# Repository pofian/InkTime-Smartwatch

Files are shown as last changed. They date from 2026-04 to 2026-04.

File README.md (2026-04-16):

# InkTime - Smartwatch

InkTime is an open-source, ultra-low-power smartwatch built around the Nordic nRF52840 SoC. It features a 1.54" E-Paper display, integrated battery management, and environmental/motion sensors, all optimized for extended battery life and BLE connectivity.

---

## Hardware Architecture

### Block Diagram

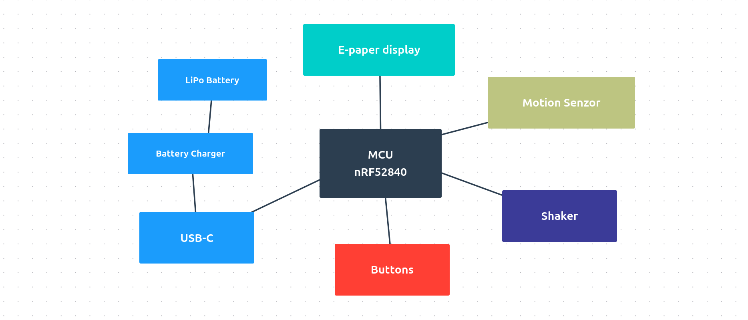
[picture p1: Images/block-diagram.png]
Block Diagram


---

## Bill of Materials

| Reference Designators | Quantity | Description | Package | Value | Manufacturer | Manufacturer Part Number | Vendor | Vendor Part Number | Top/Bottom | |
|---|---|---|---|---|---|---|---|---|---|---|
| | 1 | PCB Board | Board | | | | | | | |
| ANT1 | 1 | Antennas 2.45GHz ANTENNA | 2450AT18B100E_ANTC3216X140N | 2450AT18B100E_2450AT18B100E | | | | | Top | |
| C1, C2, C17, C18 | 4 | Generic chip capacitor | NORDIC_NRF_3_RESC0201_L | 12pF | | | | | Top | |
| C1-EP-DR, C24, C39 | 3 | CAPACITOR, European symbol | ESP32_WROVER_EAGLE-LTSPICE_C0402 | 10uF | | | | | Top | |
| C2-EP-DR | 1 | CAPACITOR, European symbol | ESP32_WROVER_EAGLE-LTSPICE_C0402 | 4.7uF/25V | | | | | Top | |
| C3, C4 | 2 | Generic chip capacitor | NORDIC_NRF_3_RESC0201_L | 1pF | | | | | Top | |
| C5, C7, C8, C12, C19 | 5 | Generic chip capacitor | NORDIC_NRF_3_RESC0201_L | 100nF | | | | | Top | |
| C6, C14, C20, C21 | 4 | Generic chip capacitor | NORDIC_NRF_3_RESC0201_L | 4.7μF | | | | | Top | |
| C9 | 1 | Generic chip capacitor | NORDIC_NRF_3_RESC0201_L | 820pF | | | | | Top | |
| C10, C13, C22 | 3 | Generic chip capacitor | NORDIC_NRF_3_RESC0201_L | N.C. | | | | | Top | |
| C11 | 1 | Generic chip capacitor | NORDIC_NRF_3_RESC0201_L | 100pF | | | | | Top | |
| C15 | 1 | Generic chip capacitor | NORDIC_NRF_3_RESC0201_L | 1.0μF | | | | | Top | |
| C16 | 1 | Generic chip capacitor | NORDIC_NRF_3_RESC0201_L | 47nF | | | | | Top | |
| C23 | 1 | Check availability | CAPC0201X13N | 0.1uF | | | | | Top | |
| C25, C33 | 2 | CAPACITOR, European symbol | ESP32_WROVER_EAGLE-LTSPICE_C0402 | 22uF | | | | | Top | |
| C27, C34 | 2 | Generic chip capacitor | NORDIC_NRF_3_RESC0201_L | 0.1uF | | | | | Top | |
| C29, C30, C31, C43 | 4 | CAPACITOR, European symbol | ESP32_WROVER_EAGLE-LTSPICE_C0402 | | | | | | Top | |
| C32, C37, C38 | 3 | CAPACITOR, European symbol | ESP32_WROVER_EAGLE-LTSPICE_C0402 | 1uF | | | | | Top | |
| C42 | 1 | Generic chip capacitor | NORDIC_NRF_3_RESC0201_L | | | | | | Top | |
| D2, D4, D5 | 3 | ON SEMICONDUCTOR - MBR0530 - DIODE, SCHOTTKY, 0.5A, 30V, SOD-123 | SOD3716X135N | ESP32_C6_LIBRARY_5_MBR0530 | | | | | Top | |
| D3 | 1 | Low Cap. ESD Protection Auto SOT-23-6 STMicroelectronics USBLC6-2SC6Y, Dual Uni-Directional TVS Diode Array, 6-Pin SOT-23 | SOT95P280X145-6N | ESP32_C6_LIBRARY_3_USBLC6-2SC6Y | | | | | Top | |
| EPD_C1, EPD_C2, EPD_C6, EPD_C7, EPD_C8, EPD_C9, EPD_C10, EPD_C11, EPD_C12 | 9 | CAPACITOR, European symbol | ESP32_WROVER_EAGLE-LTSPICE_C0402 | 1uF/50V | | | | | Top | |
| EPD_C5 | 1 | CAPACITOR, European symbol | ESP32_WROVER_EAGLE-LTSPICE_C0402 | 0.1uF/50V | | | | | Top | |
| IC1 | 1 | Charger IC Lithium Ion/Polymer, Lithium Iron Phosphate 8-DSBGA (1.6x1.1) | BQ25180YBGR_BGA8C40P2X4_100X155X50 | BQ25180YBGR_BQ25180YBGR | | | | | Top | |
| IC2 | 1 | Haptic Driver for ERM/LRA with Built-In Library and Smart Loop Architecture | DRV2605YZFR_BGA9C50P3X3_144X144X62 | DRV2605YZFR_DRV2605YZFR | | | | | Top | |
| IC3 | 1 | Accelerometers Triaxial low-g 12bit Acceleration Sensor | BMA423_BMA423 | BMA423_BMA423 | | | | | Top | |
| IC9 | 1 | Buck-Boost Regulator Positive Output Step-Up/Step-Down I2C DC-DC Controller IC 15-WL-CSP (BSC) (1.4x2.3) | RT6160AWSC_BGA15C40P3X5_140X230X60 | RT6160AWSC_RT6160AWSC | | | | | Top | |
| J1 | 1 | FFC & FPC Connectors 0.5mm FPC RA SMT Dual Contact 24Ckt | 503480-2400_5034802400 | 503480-2400_503480-2400 | | | | | Top | |
| J2 | 1 | CABLE ADAPTER 6 POS | TC2030-IDC_TC2030IDC | TC2030-IDC_TC2030-IDC | | | | | Top | |
| J4 | 1 | Check availability | KINGHELM_KH-TYPE-C-16P | KH-TYPE-C-16P_KH-TYPE-C-16P | | | | | Top | |
| L1, L7 | 2 | Generic chip inductor | NORDIC_NRF_2_RESC0402_L | | | | | | Top | |
| L2 | 1 | Generic chip inductor | NORDIC_NRF_2_RESC0402_L | 10uH | | | | | Top | |
| L3 | 1 | Generic chip inductor | NORDIC_NRF_2_RESC0402_L | 15nH | | | | | Top | |
| L5 | 1 | Generic chip inductor | NORDIC_NRF_2_RESC0402_L | 68uH | | | | | Top | |
| Q1 | 1 | P-channel MOSFETs | ESP32_WROVER_SPARKFUN-DISCRETESEMI_SOT23-3 | 20V/4.2A/52mΩ/1.4W | | | | | Top | |
| Q3 | 1 | MOSFET N-Ch 30V 1.5A TrenchFET SC70 Vishay Si1308EDL-T1-GE3 N-channel MOSFET Transistor, 1.5 A, 30 V, 3-Pin SC-70 | SOT65P210X110-3N | ESP32_C6_LIBRARY_6_SI1308EDL-T1-GE3 | | | | | Top | |
| R_PWR_EPD, R2_EP_DR, R5, R7, R8, R9 | 6 | 7.68k 0201 Thin Film Surface Mount Fixed Resistor +/-0.5% 0.031W CPF0201D7K68C1 | CPF0201D7K68C1_0201 | 10K | | | | | Top | |
| R_TYPE_SEL | 1 | 7.68k 0201 Thin Film Surface Mount Fixed Resistor +/-0.5% 0.031W CPF0201D7K68C1 | CPF0201D7K68C1_0201 | 2.2 | | | | | Top | |
| R1_EP_DR | 1 | 7.68k 0201 Thin Film Surface Mount Fixed Resistor +/-0.5% 0.031W CPF0201D7K68C1 | CPF0201D7K68C1_0201 | 0.47 | | | | | Top | |
| R1_USB, R2_USB | 2 | 7.68k 0201 Thin Film Surface Mount Fixed Resistor +/-0.5% 0.031W CPF0201D7K68C1 | CPF0201D7K68C1_0201 | 5K1 | | | | | Top | |
| R2, R4 | 2 | 7.68k 0201 Thin Film Surface Mount Fixed Resistor +/-0.5% 0.031W CPF0201D7K68C1 | CPF0201D7K68C1_0201 | 0 | | | | | Top | |
| R3 | 1 | 7.68k 0201 Thin Film Surface Mount Fixed Resistor +/-0.5% 0.031W CPF0201D7K68C1 | R0201 | 0 | | | | | Top | |
| R17, R18 | 2 | 7.68k 0201 Thin Film Surface Mount Fixed Resistor +/-0.5% 0.031W CPF0201D7K68C1 | CPF0201D7K68C1_0201 | 3K3 | | | | | Top | |
| SJ1 | 1 | SMD solder JUMPER | JUMPER_SJ | | | | | | Top | |
| SW_DN, SW_ENT, SW_UP | 3 | | SW_EVP-AKE31A_PAN | 2025-10-22_07-23-44_LIBRARY_EVP-AKE31ASW_EVP-AKE31A_PAN | | | | | Top | |
| TP_3.3V, TP_3V3, TP_BAT_GND, TP_GND, TP_ON, TP_OP, TP_RESET, TP_SCL, TP_SDA, TP_SWDCLK, TP_SWDIO, TP_SWO, TP_VBAT, TP_VREG | 14 | Test pad | HECTOR_WATCH_1_TP20R | HECTOR_WATCH_1_TPTP20R | | | | | Top | |
| U1 | 1 | nRF52840 | NORDIC_NRF_4_AQFN50P700X700X85_HS-74N | NORDIC_NRF_4_NRF52840_QF | | | | | Top | |
| U3 | 1 | Check availability | SON50P200X200X80-9N | ESP32_C6_LIBRARY_MAX17048G+T10 | | | | | Top | |
| X1 | 1 | | NORDIC_NRF_BT-XTAL_2016_N | 32MHz | | | | | Top | |
| X2 | 1 | | NORDIC_NRF_1_XTAL_3215_N | | | | | | Top | |

---

## Hardware Functionality

### 1. Power Architecture
The system is powered by a 250mAh LiPo battery.

* **Charging:** The BQ25180 manages 5V input from USB-C. It features I2C configurable charge currents and safety timers.
* **Regulation:** A high-efficiency RT6160 buck-boost converter provides a stable 3.3V rail. This maintains 3.3V even when the battery drops to 3.0V.
* **Monitoring:** The MAX17048 uses the ModelGauge algorithm to provide precise SOC (State of Charge) data.

### 2. Display System
A 1.54" E-Paper display (200x200) is used for zero power consumption when static.

* **Interface:** 4-wire SPI + DC/RST/BUSY control lines.
* **Booster Circuit:** An external inductor-based boost circuit generates the ±15V gates voltages required for the e-ink capsules.

### 3. Sensors and Feedback
* **IMU:** The BMA423 provides step counting and tilt-to-wake functionality via I2C interrupts.
* **Haptics:** The DRV2605 drives a 10mm coin vibration motor, providing tactile effects.

---

## Design Log & Decisions

### DRC Exceptions
The following errors were reviewed and manually accepted in the final design:

* **Pad-to-Trace Clearance:** Errors caused by traces passing between MCU pads; these are unavoidable due to the high-density pinout and the limited routing escape paths of the nRF52840 package.
* **Via Proximity:** Errors caused by vias placed in close proximity to each other, necessitated by the same spatial constraints in the micro-pitch area of the SoC.

### Layout Decisions
* **Stack-up:** 4-layer PCB to ensure a solid GND plane (Layer 2) for RF performance.
* **Power Traces:** All power rails (VBUS, VBAT, 3V3, etc.) use a 0.3mm width for current spikes.
* **Signal Integrity:** Data signals use 0.15mm width. No 90-degree angles were used; all corners are 45 degrees.

### Mechanical Placement
* **USB-C Port:** Centered on the top edge, slightly protruding from the PCB boundary for seamless enclosure alignment.
* **User Input:** Three tactile buttons are located on the bottom edge.

### Polygon & Outline Management
* **GND Polygon Overlaps:** Same-net (GND) clearance warnings between overlapping polygons on different layers were ignored as they pose no electrical risk.

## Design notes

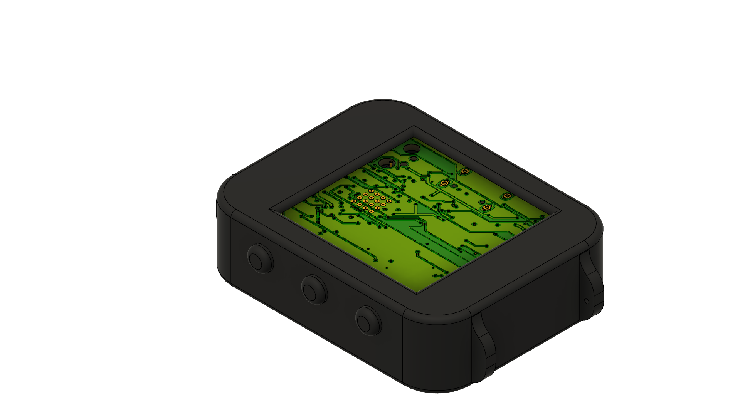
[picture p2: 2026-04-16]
Images/watch1.png

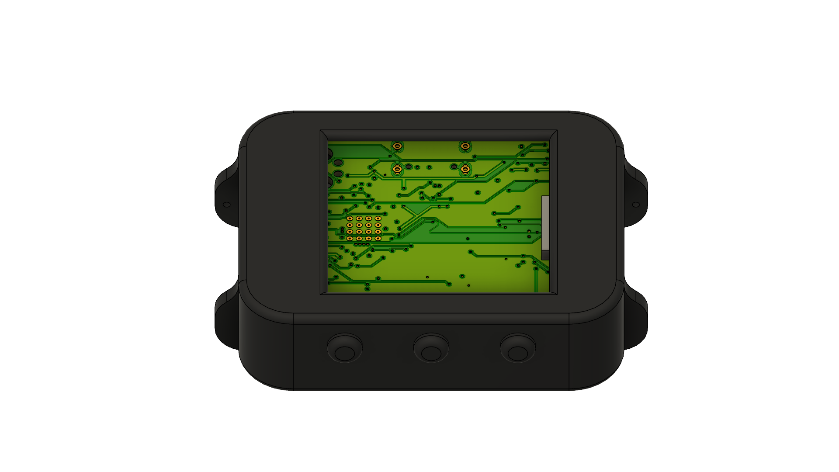
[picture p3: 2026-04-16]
Images/watch2.png

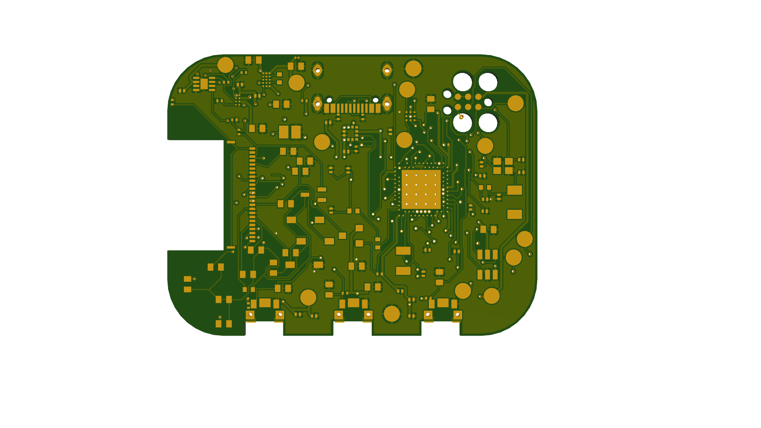
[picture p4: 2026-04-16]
Images/pcb-top.png

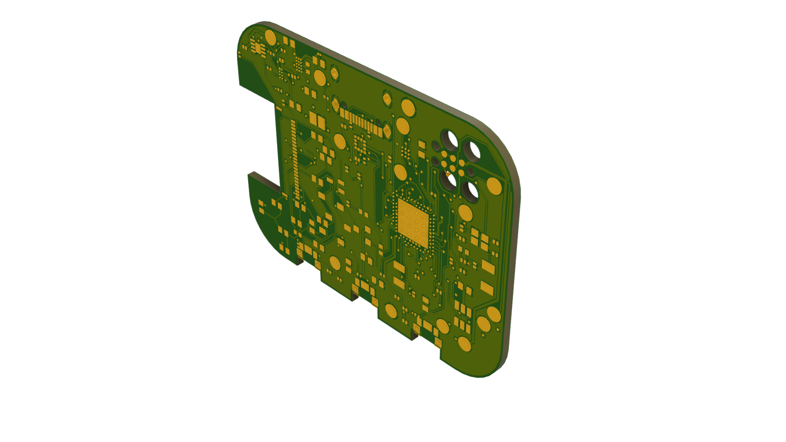
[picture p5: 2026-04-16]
Images/pcb.png

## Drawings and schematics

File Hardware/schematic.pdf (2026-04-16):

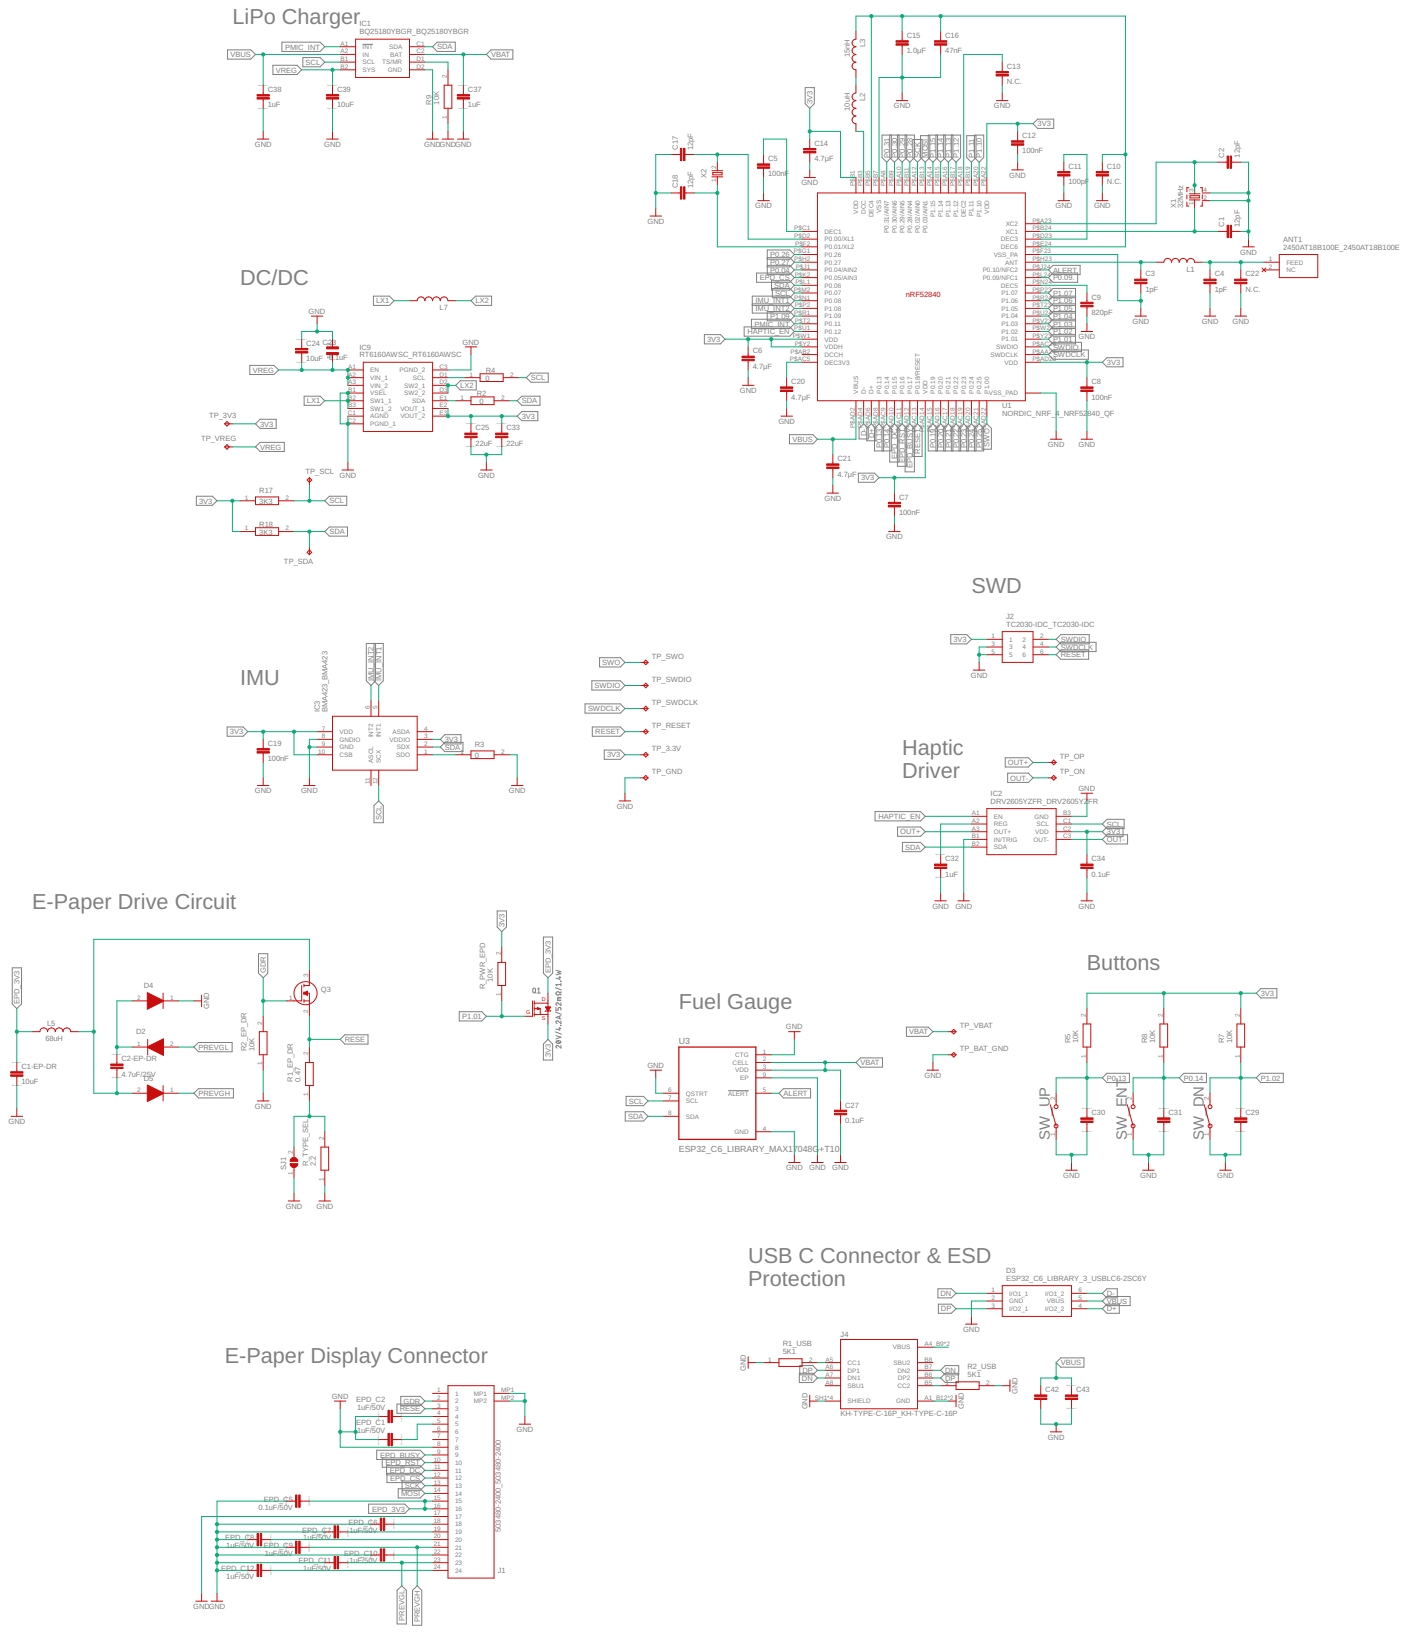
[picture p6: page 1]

10uH 15nH GND GNDGND GND GND

C1 | PGND_1 C2 | 3V3 SpiceOrder 1 SpiceOrder 1

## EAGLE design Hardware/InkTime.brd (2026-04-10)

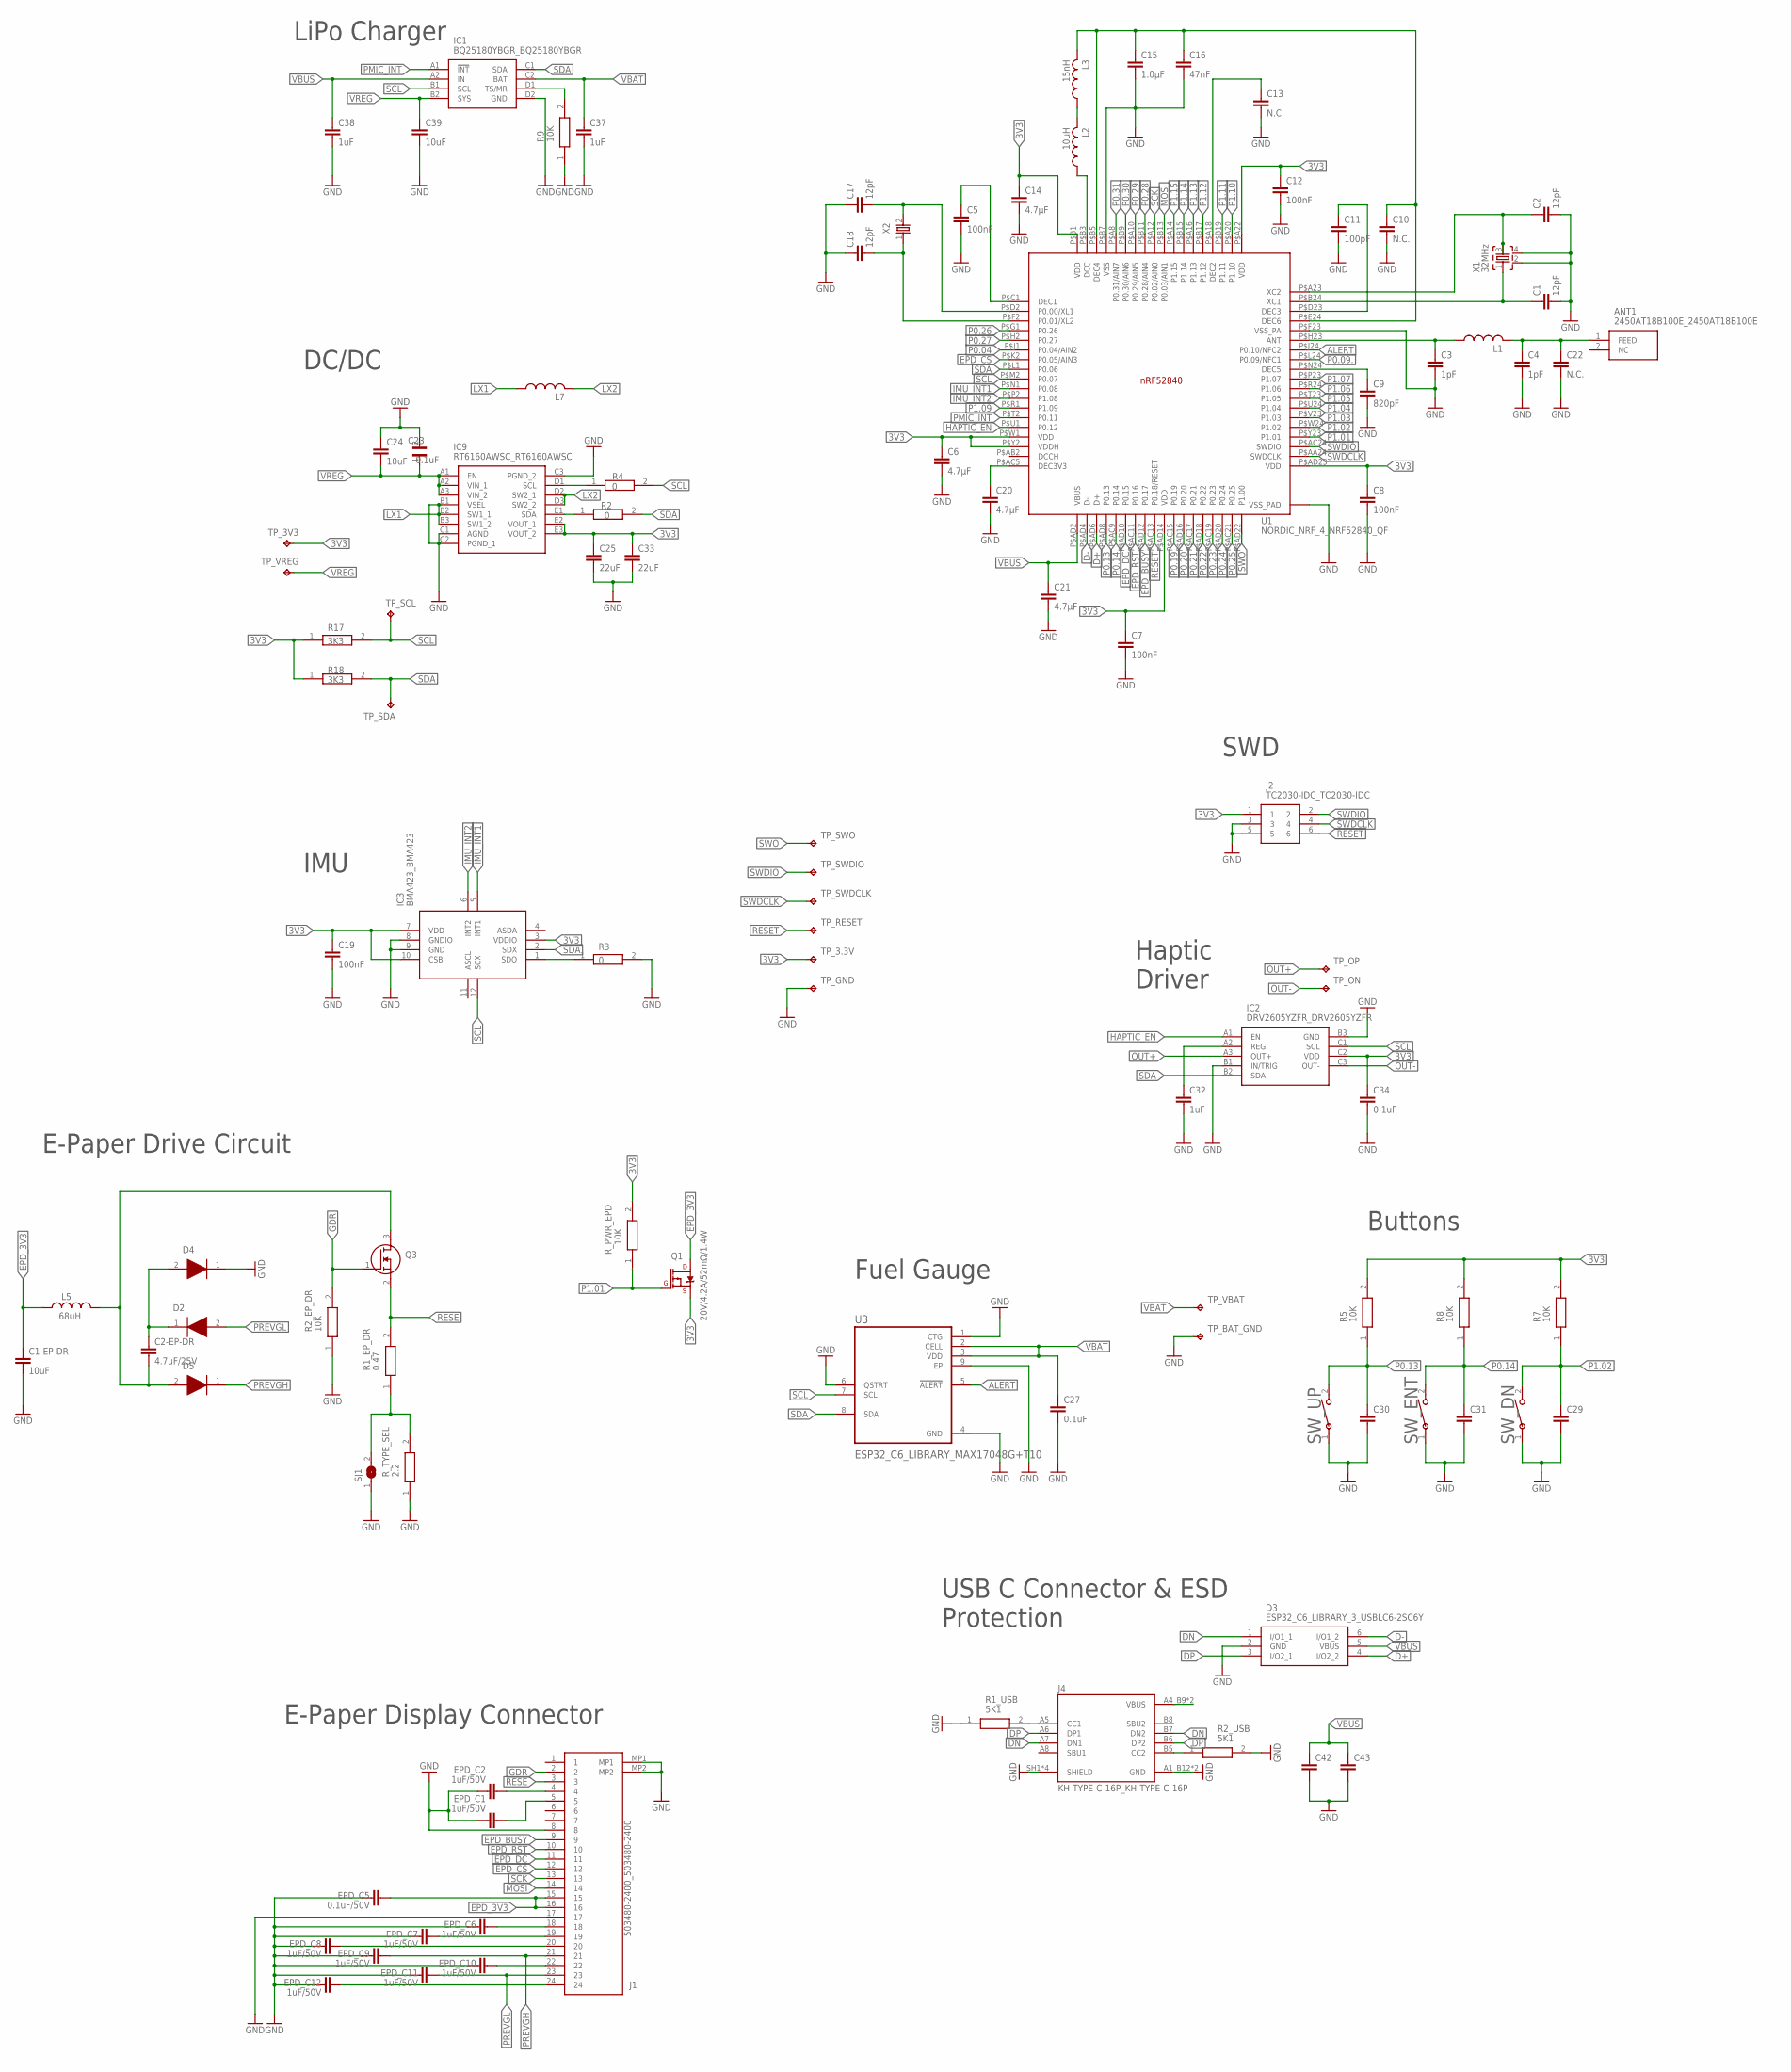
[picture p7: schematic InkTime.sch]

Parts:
ANT1: 2450AT18B100E_2450AT18B100E; 2450AT18B100E_ANTC3216X140N
C1, C2, C17, C18: 12pF; NORDIC_NRF_3_RESC0201_L
C1-EP-DR, C24, C39: 10uF; ESP32_C6_LIBRARY_1_ESP32_WROVER_EAGLE-LTSPICE_C0402
C2-EP-DR: 4.7uF/25V; ESP32_C6_LIBRARY_1_ESP32_WROVER_EAGLE-LTSPICE_C0402
C3, C4: 1pF; NORDIC_NRF_3_RESC0201_L
C5, C7, C8, C12, C19: 100nF; NORDIC_NRF_3_RESC0201_L
C6, C14, C20, C21: 4.7μF; NORDIC_NRF_3_RESC0201_L
C9: 820pF; NORDIC_NRF_3_RESC0201_L
C10, C13, C22: N.C.; NORDIC_NRF_3_RESC0201_L
C11: 100pF; NORDIC_NRF_3_RESC0201_L
C15: 1.0μF; NORDIC_NRF_3_RESC0201_L
C16: 47nF; NORDIC_NRF_3_RESC0201_L
C23: 0.1uF; GRM011R60J152KE01L_2_CAPC0201X13N
C25, C33: 22uF; ESP32_C6_LIBRARY_1_ESP32_WROVER_EAGLE-LTSPICE_C0402
C27, C34: 0.1uF; NORDIC_NRF_3_RESC0201_L
C29, C30, C31, C43: ESP32_C6_LIBRARY_1_ESP32_WROVER_EAGLE-LTSPICE_CC0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; ESP32_C6_LIBRARY_1_ESP32_WROVER_EAGLE-LTSPICE_C0402
C32, C37, C38: 1uF; ESP32_C6_LIBRARY_1_ESP32_WROVER_EAGLE-LTSPICE_C0402
C42: NORDIC_NRF_3_CAPACITOR_0201_L; NORDIC_NRF_3_RESC0201_L
D2, D4, D5: ESP32_C6_LIBRARY_5_MBR0530; ESP32_C6_LIBRARY_5_SOD3716X135N
D3: ESP32_C6_LIBRARY_3_USBLC6-2SC6Y; ESP32_C6_LIBRARY_3_SOT95P280X145-6N
EPD_C1, EPD_C2, EPD_C6, EPD_C7, EPD_C8, EPD_C9, EPD_C10, EPD_C11, EPD_C12: 1uF/50V; ESP32_C6_LIBRARY_1_ESP32_WROVER_EAGLE-LTSPICE_C0402
EPD_C5: 0.1uF/50V; ESP32_C6_LIBRARY_1_ESP32_WROVER_EAGLE-LTSPICE_C0402
IC1: BQ25180YBGR_BQ25180YBGR; BQ25180YBGR_BGA8C40P2X4_100X155X50
IC2: DRV2605YZFR_DRV2605YZFR; DRV2605YZFR_BGA9C50P3X3_144X144X62
IC3: BMA423_BMA423
IC9: RT6160AWSC_RT6160AWSC; RT6160AWSC_BGA15C40P3X5_140X230X60
J1: 503480-2400_503480-2400; 503480-2400_5034802400
J2: TC2030-IDC_TC2030-IDC; TC2030-IDC_TC2030IDC
J4: KH-TYPE-C-16P_KH-TYPE-C-16P; KH-TYPE-C-16P_KINGHELM_KH-TYPE-C-16P
L1, L7: NORDIC_NRF_2_INDUCTOR_0402_L; NORDIC_NRF_2_RESC0402_L
L2: 10uH; NORDIC_NRF_2_RESC0402_L
L3: 15nH; NORDIC_NRF_2_RESC0402_L
L5: 68uH; NORDIC_NRF_2_RESC0402_L
Q1: 20V/4.2A/52mΩ/1.4W; ESP32_C6_LIBRARY_4_ESP32_C6_LIBRARY_4_ESP32_C6_LIBRARY_4_ES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
Q3: ESP32_C6_LIBRARY_6_SI1308EDL-T1-GE3; ESP32_C6_LIBRARY_6_SOT65P210X110-3N
R1_EP_DR: 0.47; CPF0201D7K68C1_0201
R1_USB, R2_USB: 5K1; CPF0201D7K68C1_0201
R2, R4: 0; CPF0201D7K68C1_0201
R2_EP_DR, R5, R7, R8, R9: 10K; CPF0201D7K68C1_0201
R3: 0; ERA-1AEB3401C_0201
R17, R18: 3K3; CPF0201D7K68C1_0201
R_PWR_EPD: 10K; CPF0201D7K68C1_0201
R_TYPE_SEL: 2.2; CPF0201D7K68C1_0201
SJ1: ESP32_C6_LIBRARY_7_JUMPER_SJ
SW_DN: 2025-10-22_07-23-44_LIBRARY_EVP-AKE31ASW_EVP-AKE3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; 2025-10-22_07-23-44_LIBRARY_SW_EVP-AKE31A_PAN
SW_ENT: 2025-10-22_07-23-44_LIBRARY_EVP-AKE31ASW_EVP-AKE3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; 2025-10-22_07-23-44_LIBRARY_SW_EVP-AKE31A_PAN
SW_UP: 2025-10-22_07-23-44_LIBRARY_EVP-AKE31ASW_EVP-AKE3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; 2025-10-22_07-23-44_LIBRARY_SW_EVP-AKE31A_PAN
TP_3.3V, TP_3V3: HECTOR_WATCH_1_TPTP20R; HECTOR_WATCH_1_TP20R
TP_BAT_GND: HECTOR_WATCH_1_TPTP20R; HECTOR_WATCH_1_TP20R
TP_GND: HECTOR_WATCH_1_TPTP20R; HECTOR_WATCH_1_TP20R
TP_ON: HECTOR_WATCH_1_TPTP20R; HECTOR_WATCH_1_TP20R
TP_OP: HECTOR_WATCH_1_TPTP20R; HECTOR_WATCH_1_TP20R
TP_RESET: HECTOR_WATCH_1_TPTP20R; HECTOR_WATCH_1_TP20R
TP_SCL: HECTOR_WATCH_1_TPTP20R; HECTOR_WATCH_1_TP20R
TP_SDA: HECTOR_WATCH_1_TPTP20R; HECTOR_WATCH_1_TP20R
TP_SWDCLK: HECTOR_WATCH_1_TPTP20R; HECTOR_WATCH_1_TP20R
TP_SWDIO: HECTOR_WATCH_1_TPTP20R; HECTOR_WATCH_1_TP20R
TP_SWO: HECTOR_WATCH_1_TPTP20R; HECTOR_WATCH_1_TP20R
TP_VBAT: HECTOR_WATCH_1_TPTP20R; HECTOR_WATCH_1_TP20R
TP_VREG: HECTOR_WATCH_1_TPTP20R; HECTOR_WATCH_1_TP20R
U1: NORDIC_NRF_4_NRF52840_QF; NORDIC_NRF_4_AQFN50P700X700X85_HS-74N
U3: ESP32_C6_LIBRARY_MAX17048G+T10; ESP32_C6_LIBRARY_SON50P200X200X80-9N
X1: 32MHz; NORDIC_NRF_BT-XTAL_2016_N
X2: NORDIC_NRF_1_XTAL_32KHZ; NORDIC_NRF_1_XTAL_3215_N

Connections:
3V3: C6.1, C7.1, C8.1, C12.1, C14.1, C19.1, C25.1, C33.1, C34.1, IC2.C2 (VDD), IC3.3 (VDDIO), IC3.7 (VDD), IC3.10 (CSB), IC9.E2 (VOUT_1), IC9.E3 (VOUT_2), J2.1, Q1.2 (S), R5.2, R7.2, R8.2, R17.1, R18.1, R_PWR_EPD.2, TP_3.3V.TP, TP_3V3.TP, U1.P$A22 (VDD), U1.P$AD14 (VDD), U1.P$AD23 (VDD), U1.P$B1 (VDD), U1.P$W1 (VDD), U1.P$Y2 (VDDH)
ALERT: U1.P$J24 (P0.10/NFC2), U3.5 (!ALERT)
D+: D3.4 (I/O2_2), U1.P$AD6 (D+)
D-: D3.6 (I/O1_2), U1.P$AD4 (D-)
DN: D3.1 (I/O1_1), J4.A7 (DN1), J4.B7 (DN2)
DP: D3.3 (I/O2_1), J4.A6 (DP1), J4.B6 (DP2)
EPD_3V3: C1-EP-DR.1, EPD_C5.2, J1.15, J1.16, L5.1, Q1.3 (D)
EPD_BUSY: J1.9, U1.P$AD12 (P0.17)
EPD_CS: J1.12, U1.P$K2 (P0.05/AIN3)
EPD_DC: J1.11, U1.P$AD10 (P0.15)
EPD_RST: J1.10, U1.P$AC11 (P0.16)
GDR: J1.1, J1.2, J1.MP1, J1.MP2, Q3.1 (G), R2_EP_DR.2
GND: C1.2, C1-EP-DR.2, C2.2, C3.2, C4.2, C5.2, C6.2, C7.2, C8.2, C9.2, C10.2, C11.2, C12.2, C13.2, C14.2, C15.2, C16.2, C17.1, C18.1, C19.2, C20.2, C21.2, C22.2, C23.2, C24.1, C25.2, C27.2, C29.2, C30.2, C31.2, C32.2, C33.2, C34.2, C37.2, C38.2, C39.2, C42.2, C43.2, D3.2 (GND), D4.1 (K), EPD_C1.1, EPD_C2.1, IC1.D2 (GND), IC2.B1 (IN/TRIG), IC2.B3 (GND), IC3.8 (GNDIO), IC3.9 (GND), IC9.C3 (PGND_2), J1.8, J1.17, J2.3, J2.5, J4.A1_B12 (GND), J4.A12_B1 (GND), J4.SH1 (SHIELD), J4.SH2 (SHIELD), J4.SH3 (SHIELD), J4.SH4 (SHIELD), R1_USB.1, R2_EP_DR.1, R2_USB.2, R3.2, R9.1, R_TYPE_SEL.1, SJ1.1, SW_DN.1, SW_ENT.1, SW_UP.1, TP_BAT_GND.TP, TP_GND.TP, U1.P$74 (VSS_PAD), U1.P$75 (VSS_PAD), U1.P$76 (VSS_PAD), U1.P$77 (VSS_PAD), U1.P$78 (VSS_PAD), U1.P$79 (VSS_PAD), U1.P$80 (VSS_PAD), U1.P$81 (VSS_PAD), U1.P$82 (VSS_PAD), U1.P$83 (VSS_PAD), U1.P$84 (VSS_PAD), U1.P$85 (VSS_PAD), U1.P$86 (VSS_PAD), U1.P$87 (VSS_PAD), U1.P$88 (VSS_PAD), U1.P$89 (VSS_PAD), U1.P$90 (VSS_PAD), U1.P$B7 (VSS), U1.P$F23 (VSS_PA), U3.1 (CTG), U3.4 (GND), U3.6 (QSTRT), U3.9 (EP), X1.2, X1.4
HAPTIC_EN: IC2.A1 (EN), U1.P$U1 (P0.12)
IMU_INT1: IC3.5 (INT1), U1.P$N1 (P0.08)
IMU_INT2: IC3.6 (INT2), U1.P$P2 (P1.08)
LX1: IC9.B1 (VSEL), IC9.B2 (SW1_1), IC9.B3 (SW1_2), IC9.C1 (AGND), IC9.C2 (PGND_1), L7.1
LX2: IC9.D2 (SW2_1), IC9.D3 (SW2_2), L7.2
MOSI: J1.14, U1.P$B13 (P0.03/AIN1)
unnamed: L2.1, U1.P$B3 (DCC)
unnamed: C5.1, U1.P$C1 (DEC1)
unnamed: L2.2, L3.1
unnamed: C10.1, C15.1, C16.1, L3.2, U1.P$B5 (DEC4), U1.P$E24 (DEC6)
unnamed: C2-EP-DR.1, D2.1 (K), D4.2 (A)
unnamed: C13.1, U1.P$A18 (DEC2)
unnamed: IC9.D1 (SCL), R4.1
unnamed: C11.1, U1.P$D23 (DEC3)
unnamed: C32.1, IC2.A2 (REG)
unnamed: IC9.E1 (SDA), R2.1
unnamed: IC1.D1 (TS/MR), R9.2
unnamed: EPD_C6.2, J1.18
unnamed: EPD_C7.2, J1.19
unnamed: EPD_C8.2, J1.20
unnamed: IC3.1 (SDO), R3.1
unnamed: C2-EP-DR.2, D5.2 (A), L5.2, Q3.3 (D)
unnamed: J4.A5 (CC1), R1_USB.2
unnamed: J4.A4_B9 (VBUS), J4.A9_B4 (VBUS)
unnamed: C17.2, U1.P$D2 (P0.00/XL1), X2.2
unnamed: C18.2, U1.P$F2 (P0.01/XL2), X2.1
unnamed: EPD_C10.2, J1.22
unnamed: C20.1, U1.P$AC5 (DEC3V3)
unnamed: C2.1, U1.P$A23 (XC2), X1.3
unnamed: J4.B5 (CC2), R2_USB.1
unnamed: EPD_C12.2, J1.24
unnamed: C1.1, U1.P$B24 (XC1), X1.1
unnamed: ANT1.1 (FEED), C4.1, C22.1, L1.2
unnamed: C9.1, U1.P$N24 (DEC5)
unnamed: C3.1, L1.1, U1.P$H23 (ANT)
unnamed: EPD_C1.2, J1.5
unnamed: EPD_C2.2, J1.4
unnamed: R1_EP_DR.1, R_TYPE_SEL.2, SJ1.2
OUT+: IC2.A3 (OUT+), TP_OP.TP
OUT-: IC2.C3 (OUT-), TP_ON.TP
P0.04: U1.P$J1 (P0.04/AIN2)
P0.09.: U1.P$L24 (P0.09/NFC1)
P0.13: C30.1, R5.1, SW_UP.2, U1.P$AD8 (P0.13)
P0.14: C31.1, R8.1, SW_ENT.2, U1.P$AC9 (P0.14)
P0.19: U1.P$AC15 (P0.19)
P0.20: U1.P$AD16 (P0.20)
P0.21: U1.P$AC17 (P0.21)
P0.22: U1.P$AD18 (P0.22)
P0.23: U1.P$AC19 (P0.23)
P0.24: U1.P$AD20 (P0.24)
P0.25: U1.P$AC21 (P0.25)
P0.26: U1.P$G1 (P0.26)
P0.27: U1.P$H2 (P0.27)
P0.28: U1.P$B11 (P0.28/AIN4)
P0.29: U1.P$A10 (P0.29/AIN5)
P0.30: U1.P$B9 (P0.30/AIN6)
P0.31: U1.P$A8 (P0.31/AIN7)
P1.01: Q1.1 (G), R_PWR_EPD.1, U1.P$Y23 (P1.01)
P1.02: C29.1, R7.1, SW_DN.2, U1.P$W24 (P1.02)
P1.03: U1.P$V23 (P1.03)
P1.04: U1.P$U24 (P1.04)
P1.05: U1.P$T23 (P1.05)
P1.06: U1.P$R24 (P1.06)
P1.07: U1.P$P23 (P1.07)
P1.09: U1.P$R1 (P1.09)
P1.10: U1.P$A20 (P1.10)
P1.11: U1.P$B19 (P1.11)
P1.12: U1.P$B17 (P1.12)
P1.13: U1.P$A16 (P1.13)
P1.14: U1.P$B15 (P1.14)
P1.15: U1.P$A14 (P1.15)
PMIC_INT: IC1.A1 (!INT), U1.P$T2 (P0.11)
PREVGH: D5.1 (K), EPD_C9.2, J1.21
PREVGL: D2.2 (A), EPD_C5.1, EPD_C6.1, EPD_C7.1, EPD_C8.1, EPD_C9.1, EPD_C10.1, EPD_C11.1, EPD_C11.2, EPD_C12.1, J1.23
RESE: J1.3, Q3.2 (S), R1_EP_DR.2
RESET: J2.6, TP_RESET.TP, U1.P$AC13 (P0.18/RESET)
SCK: J1.13, U1.P$A12 (P0.02/AIN0)
SCL: IC1.B1 (SCL), IC2.C1 (SCL), IC3.12 (SCX), R4.2, R17.2, TP_SCL.TP, U1.P$M2 (P0.07), U3.7 (SCL)
SDA: IC1.C1 (SDA), IC2.B2 (SDA), IC3.2 (SDX), R2.2, R18.2, TP_SDA.TP, U1.P$L1 (P0.06), U3.8 (SDA)
SWDCLK: J2.4, TP_SWDCLK.TP, U1.P$AA24 (SWDCLK)
SWDIO: J2.2, TP_SWDIO.TP, U1.P$AC24 (SWDIO)
SWO: TP_SWO.TP, U1.P$AD22 (P1.00)
VBAT: C27.1, C37.1, IC1.C2 (BAT), TP_VBAT.TP, U3.2 (CELL), U3.3 (VDD)
VBUS: C21.1, C38.1, C42.1, C43.1, D3.5 (VBUS), IC1.A2 (IN), U1.P$AD2 (VBUS)
VREG: C23.1, C24.2, C39.1, IC1.B2 (SYS), IC9.A1 (EN), IC9.A2 (VIN_1), IC9.A3 (VIN_2), TP_VREG.TP

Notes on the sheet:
LiPo Charger
DC/DC
IMU
SWD
Haptic Driver
Buttons
Fuel Gauge
E-Paper Drive Circuit
E-Paper Display Connector
USB C Connector & ESD Protection

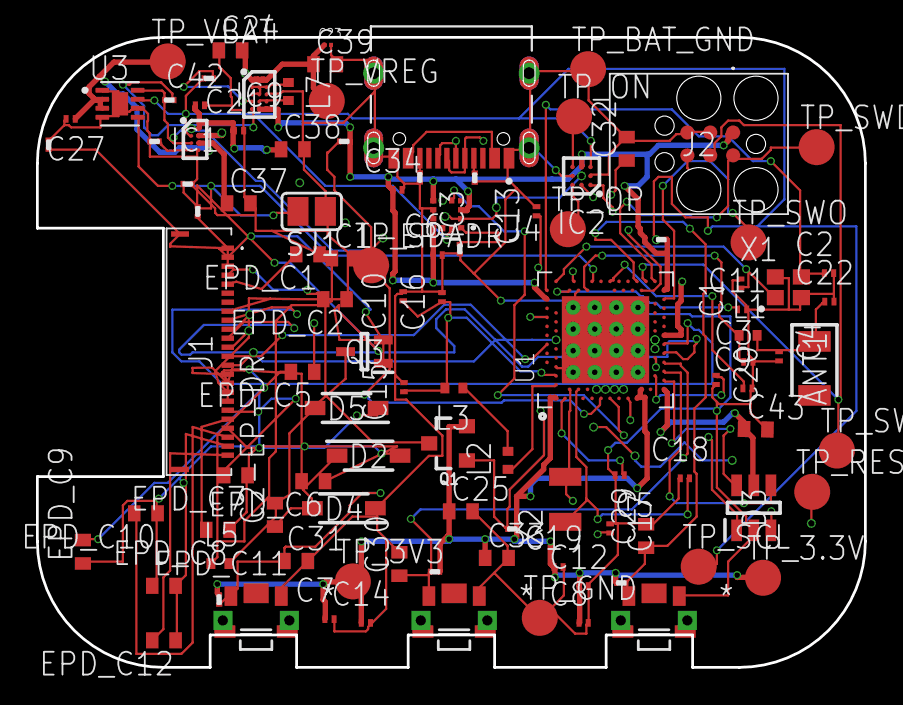
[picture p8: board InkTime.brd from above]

Board: 4 copper layers, 46.0 x 35.0 mm, 105 parts (0 on the bottom side), 71 nets.

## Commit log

2026-04-10 Finish Schematic & Add PCB
    [InkTime.brd, InkTime.sch]
2026-04-16 Finish PCB & Add 3D Design
    [bill-of-materials.csv]

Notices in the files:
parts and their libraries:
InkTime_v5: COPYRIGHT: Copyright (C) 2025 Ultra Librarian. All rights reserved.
